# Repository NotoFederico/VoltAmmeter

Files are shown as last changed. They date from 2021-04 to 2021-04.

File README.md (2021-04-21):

# VoltAmmeter

Medidor de tensión y corriente de precisión para fuente de alimentación implementado con placa de desarrollo BLUEPILL (STM32F103)
---

Project.Cover

---

### Download
| Latest release | Latest development build |
|---|---|
|  |  |

---

# Contents
- 1 - [Introduction](#1-introduction)
- 2 - [Downloading the application](#2-downloading-the-game-pre-built)
- 3 - [Building the game](#3-building-the-game)
  - 3.1 - [Building prerequisites](#31-building-prerequisites)
  - 3.2 - [Compiling and running](#32-compiling-and-running)
- 4 - [Contributing](#4-contributing)
- 5 - [Licence](#5-licence)

---

# 1. Introduction

Utiliza un módulo ADS1115 (ADC 16 bits) para la lectura diferencial de corriente y la lectura de tensión de una fuente de alimentación regulable de 0V a 60V y de 0A a 5A.
A través de una comunicación I2C los datos son procesados por el microprocesador a través de un simple algoritmo de promedio de muestras.

Está en curso una segunda versión con tecnologia SMD y se está estudiando implementar un algoritmo que obtenga el promedio de manera mas eficiente

---

# 2. Downloading the application

---

# 3. Building the application

## 3.1 Building prerequisites

---

## 3.2 Compiling and running

---

# 4. Contributing

---
# 5. Licence

Pong Game is licensed under the GNU General Public License version 3.

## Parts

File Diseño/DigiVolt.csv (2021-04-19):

Item | Qty | Reference(s) | Value | Footprint | Available
1 | 3 | AP1, EA1, EV1 | Conn_01x02 | Connectors_Terminal_Blocks:TerminalBlock_Altech_AK300-2_P5.00mm | Yes
2 | 5 | C2, C8, C9, C10, C11 | 0.1u | Capacitors_SMD:C_1206_HandSoldering | No
3 | 2 | C3, C5 | 0.022u | Capacitors_SMD:C_1206_HandSoldering | No
4 | 1 | C4 | 0.22u | Capacitors_SMD:C_1206_HandSoldering | No
5 | 1 | C6 | 3.9n | Capacitors_SMD:C_1206_HandSoldering | No
6 | 1 | J4 | Conn_01x12_Female | Socket_Strips:Socket_Strip_Straight_1x12_Pitch2.54mm | Yes
7 | 1 | J5 | Conn_01x10_Female | Socket_Strips:Socket_Strip_Straight_1x10_Pitch2.54mm | Yes
8 | 2 | J6, J7 | Conn_01x27_Female | Socket_Strips:Socket_Strip_Straight_1x27_Pitch2.54mm | No
9 | 3 | JP1, JP2, JP3 | Jumper | Pin_Headers:Pin_Header_Straight_1x02_Pitch2.54mm | Yes
10 | 1 | R1 | 15k | Resistors_SMD:R_1206_HandSoldering | No
11 | 1 | R2 | 1k | Resistors_SMD:R_1206_HandSoldering | No
12 | 1 | R3 | 0R | Resistors_SMD:R_1206_HandSoldering | No
13 | 1 | R4 | 150k | Resistors_SMD:R_1206_HandSoldering | No
14 | 2 | R5, R6 | 1.2k | Resistors_SMD:R_1206_HandSoldering | No
15 | 2 | R7, R8 | 8.2k | Resistors_SMD:R_1206_HandSoldering | No
16 | 2 | R9, R10 | 100 | Resistors_SMD:R_1206_HandSoldering | No
17 | 1 | R11 | 12k | Resistors_SMD:R_1206_HandSoldering | No
18 | 2 | R12, R13 | 10k | Resistors_SMD:R_1206_HandSoldering | No
19 | 1 | R14 | 100k | Resistors_SMD:R_1206_HandSoldering | No
20 | 1 | RV1 | POT | Potentiometers:Potentiometer_Trimmer_Bourns_3296W | No
21 | 1 | Shunt1 | 0.05 | SMD4527:SMD-1206_Pol | No
22 | 1 | U1 | MC33078 | Housings_DIP:DIP-8_W10.16mm_LongPads | No
23 | 1 | U3 | LM358 | Housings_DIP:DIP-8_W10.16mm_LongPads | No

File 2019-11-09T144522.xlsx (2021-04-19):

Index | Quantity | Part Number | Manufacturer Part Number | Description | Customer Reference | Available | Backorder | Unit Price | Extended Price USD
1 | 4 | 732-7914-1-ND | 885012106017 | CAP CER 1UF 16V X5R 0603 |  | 4 | 0 | 0.15 | 0.60
2 | 1 | 811-3014-ND | OKI-78SR-3.3/1.5-W36H-C | DC DC CONVERTER 3.3V 5W |  | 1 | 0 | 4.3 | 4.30
3 | 1 | 811-2692-ND | OKI-78SR-5/1.5-W36H-C | DC DC CONVERTER 5V 8W |  | 1 | 0 | 4.3 | 4.30
4 | 4 | A126389CT-ND | CRG0805F8K2 | RES SMD 8.2K OHM 1% 1/8W 0805 |  | 4 | 0 | 0.1 | 0.40
5 | 4 | A129737CT-ND | CRGCQ0805F100R | CRGCQ 0805 100R 1% |  | 4 | 0 | 0.1 | 0.40
6 | 10 | A129761CT-ND | CRGCQ0805F10K | CRGCQ 0805 10K 1% |  | 10 | 0 | 0.051 | 0.51
7 | 2 | MCP6241T-E/SNCT-ND | MCP6241T-E/SN | IC OPAMP GP 1 CIRCUIT 8SOIC |  | 2 | 0 | 0.3 | 0.60
8 | 10 | 311-1338-1-ND | CC0402KRX7R7BB104 | CAP CER 0.1UF 16V X7R 0402 |  | 10 | 0 | 0.03 | 0.30
9 | 2 | A129763CT-ND | CRGCQ0805F15K | CRGCQ 0805 15K 1% |  | 2 | 0 | 0.1 | 0.20
10 | 2 | A126340CT-ND | CRG0805F150K | RES SMD 150K OHM 1% 1/8W 0805 |  | 2 | 0 | 0.1 | 0.20
11 | 2 | A129749CT-ND | CRGCQ0805F1K0 | CRGCQ 0805 1K0 1% |  | 2 | 0 | 0.1 | 0.20
12 | 4 | A126346CT-ND | CRG0805F1K2 | RES SMD 1.2K OHM 1% 1/8W 0805 |  | 4 | 0 | 0.1 | 0.40
13 | 2 | 311-1.50MCRCT-ND | RC0805FR-071M5L | RES SMD 1.5M OHM 1% 1/8W 0805 |  | 2 | 0 | 0.1 | 0.20
14 | 2 | 497-8716-1-ND | LD39050PU33R | IC REG LINEAR 3.3V 500MA 6DFN |  | 2 | 0 | 1.09 | 2.18
15 | 2 | 505-AD8628WARZ-R7CT-ND | AD8628WARZ-R7 | IC OPAMP ZERO-DRIFT 1 CIRC 8SOIC |  | 2 | 0 | 2.87 | 5.74
16 | 1 | AZ1117EH-3.3TRG1DICT-ND | AZ1117EH-3.3TRG1 | IC REG LINEAR 3.3V 1A SOT223 |  | 1 | 0 | 0.42 | 0.42
17 | 1 | AZ1117EH-5.0TRG1DICT-ND | AZ1117EH-5.0TRG1 | IC REG LINEAR 5V 1A SOT223 |  | 1 | 0 | 0.42 | 0.42

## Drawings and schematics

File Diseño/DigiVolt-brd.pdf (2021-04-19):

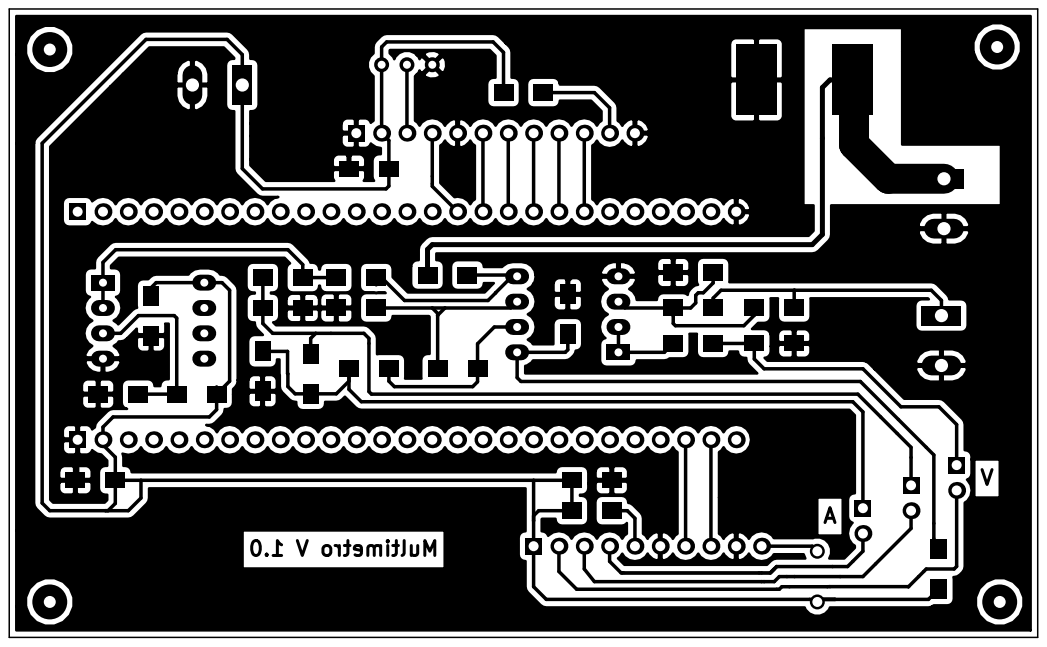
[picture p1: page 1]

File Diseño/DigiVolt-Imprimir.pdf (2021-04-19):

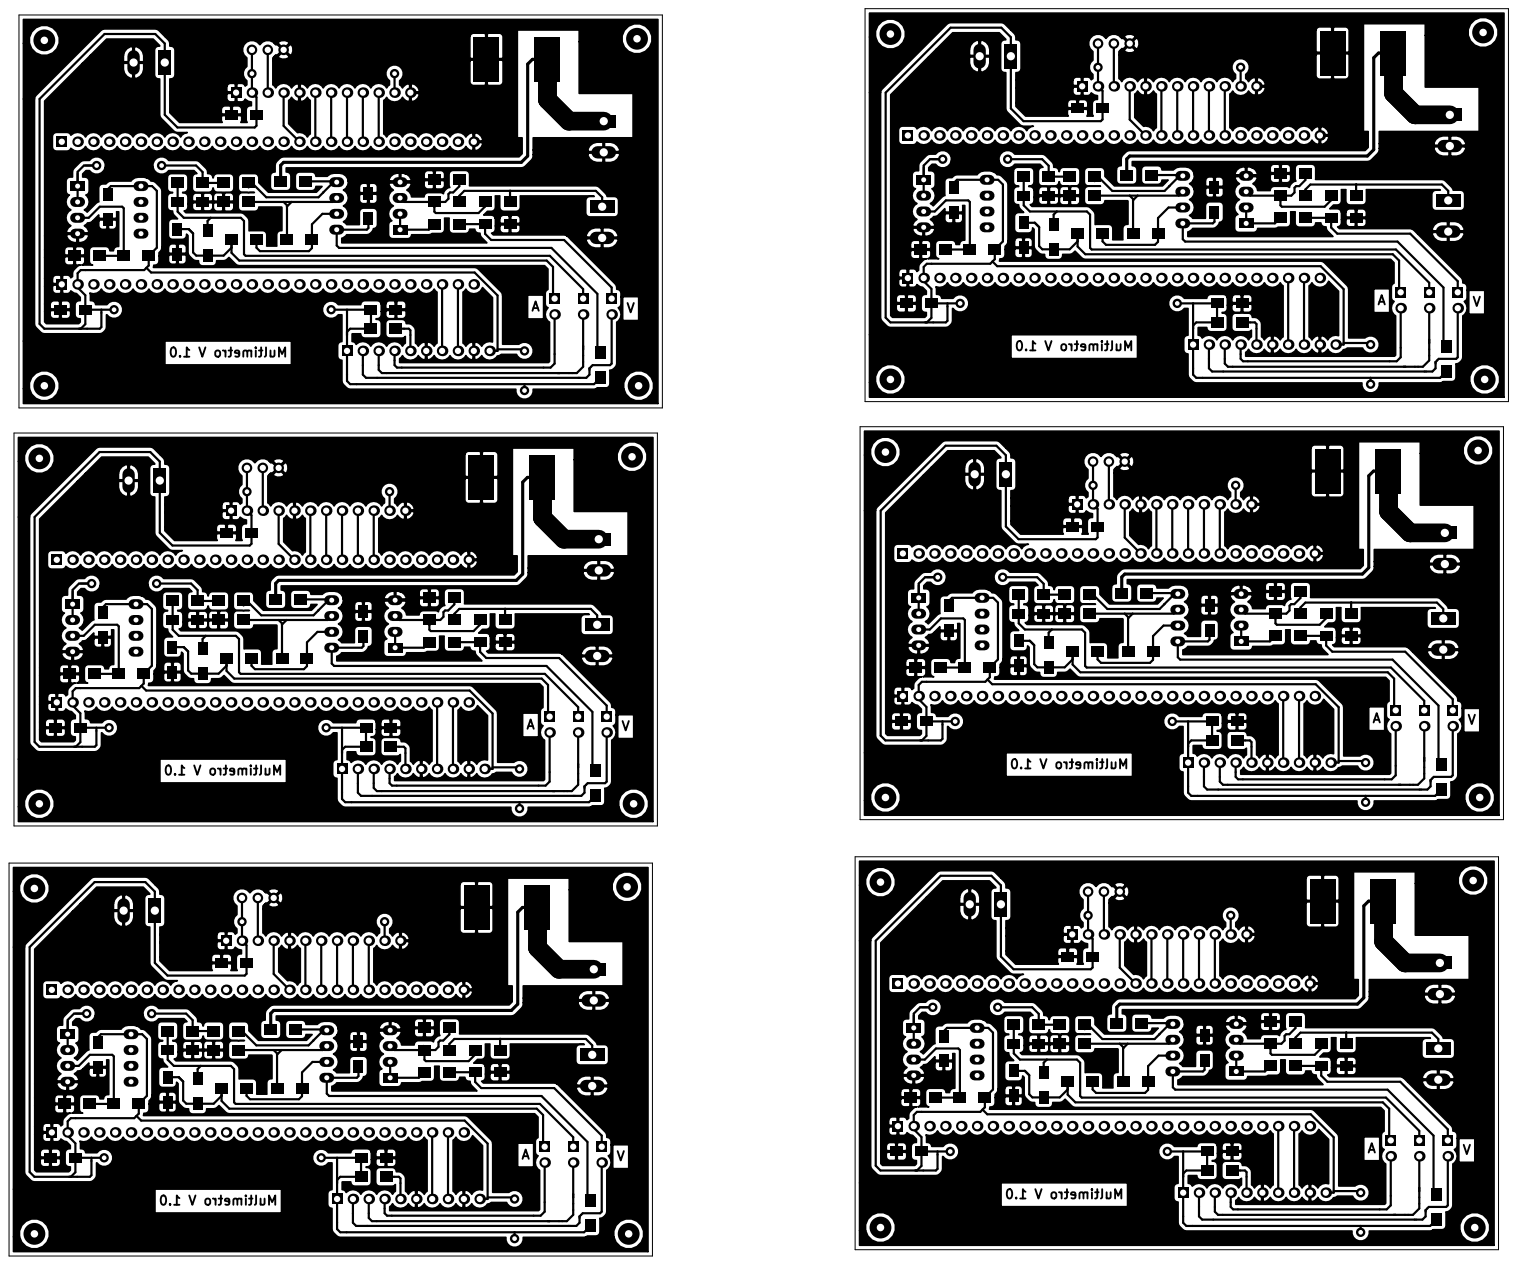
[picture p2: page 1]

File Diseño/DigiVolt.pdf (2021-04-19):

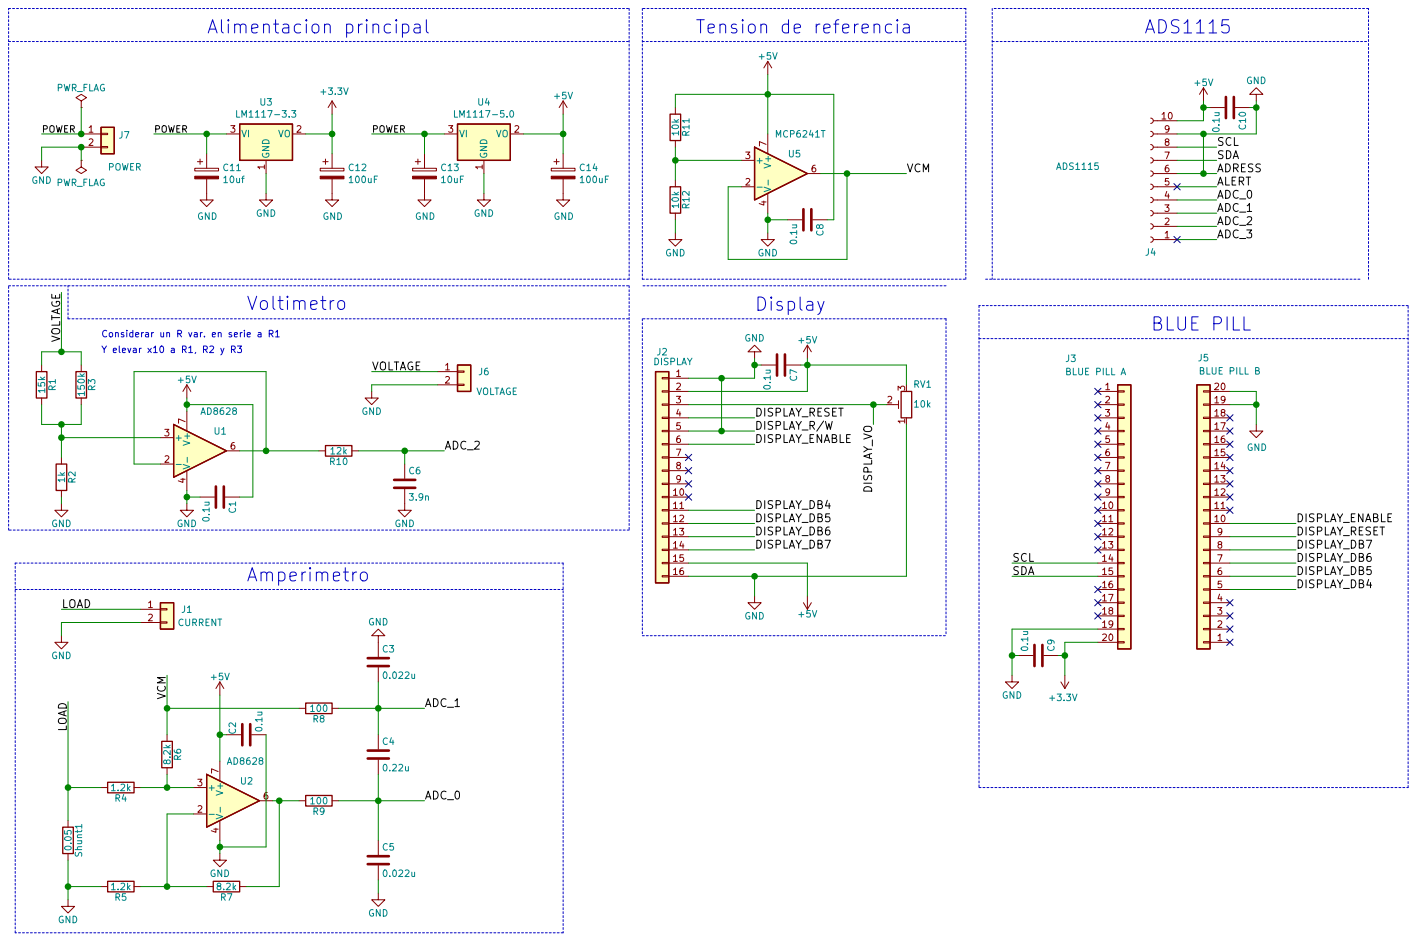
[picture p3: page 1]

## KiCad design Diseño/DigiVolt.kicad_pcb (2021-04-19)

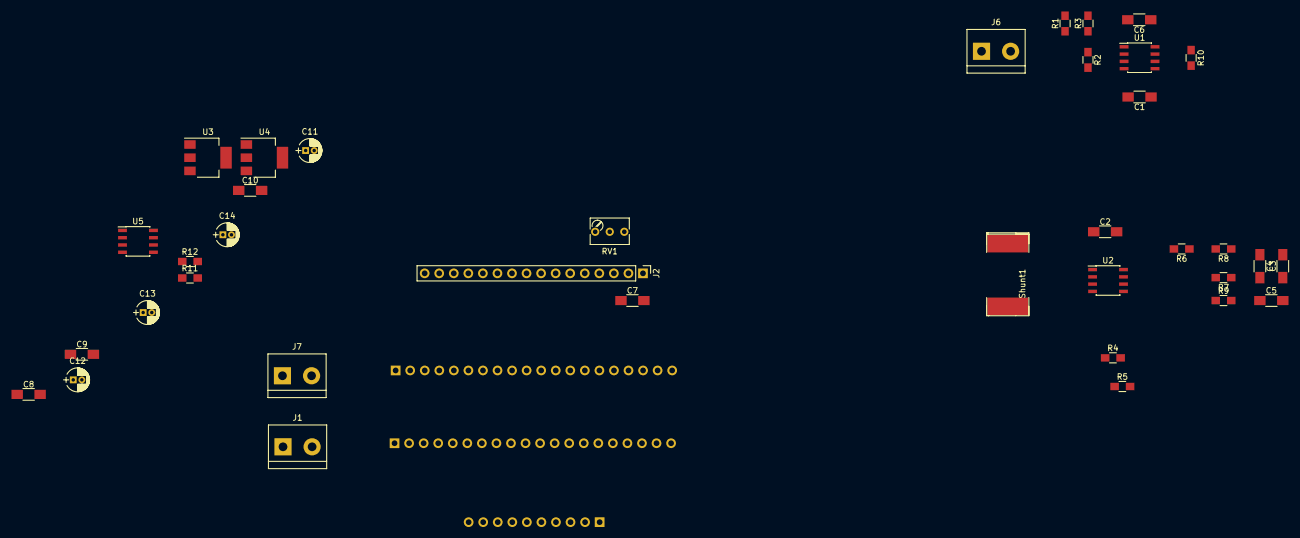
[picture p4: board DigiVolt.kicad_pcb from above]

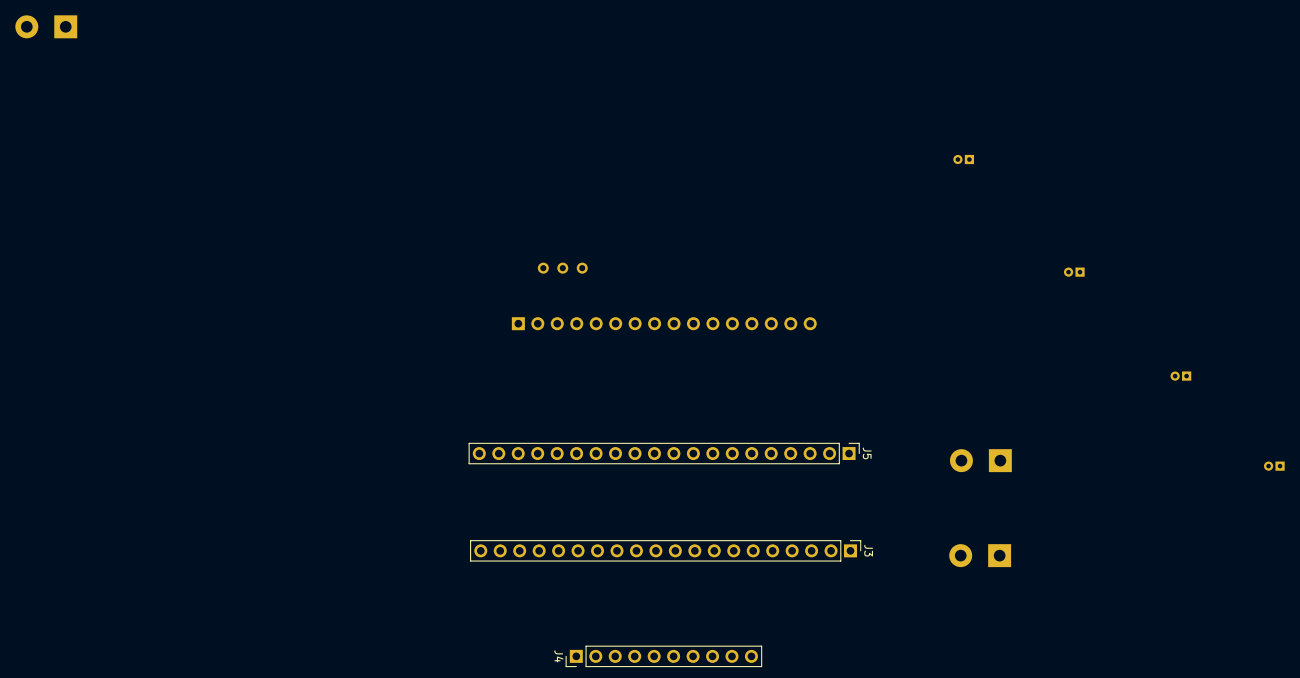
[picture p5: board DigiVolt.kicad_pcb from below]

Board: 4 copper layers, 40 parts (3 on the bottom side), 25 nets, no tracks yet.

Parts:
C1, C2, C7, C8, C9, C10: 0.1u; C_1206_HandSoldering
C3, C5: 0.022u; C_1206_HandSoldering
C4: 0.22u; C_1206_HandSoldering
C6: 3.9n; C_1206_HandSoldering
C11: 10uf; CP_Radial_D4.0mm_P1.50mm
C12, C14: 100uF; CP_Radial_D4.0mm_P1.50mm
C13: 10uF; CP_Radial_D4.0mm_P1.50mm
J1: CURRENT; TerminalBlock_bornier-2_P5.08mm
J2: DISPLAY; Socket_Strip_Straight_1x16_Pitch2.54mm
J3: BLUE PILL A; Socket_Strip_Straight_1x20_Pitch2.54mm
J4: ADS1115; Socket_Strip_Straight_1x10_Pitch2.54mm
J5: BLUE PILL B; Socket_Strip_Straight_1x20_Pitch2.54mm
J6: VOLTAGE; TerminalBlock_bornier-2_P5.08mm
J7: POWER; TerminalBlock_bornier-2_P5.08mm
R1: 15k; R_0805_HandSoldering
R2: 1k; R_0805_HandSoldering
R3: 150k; R_0805_HandSoldering
R4, R5: 1.2k; R_0805_HandSoldering
R6, R7: 8.2k; R_0805_HandSoldering
R8, R9: 100; R_0805_HandSoldering
R10: 12k; R_0805_HandSoldering
R11, R12: 10k; R_0805_HandSoldering
RV1: 10k; Potentiometer_Trimmer_Bourns_3266Y
Shunt1: 0.05; SMD-1206_Pol
U1, U2: AD8628; SOIC-8_3.9x4.9mm_Pitch1.27mm
U3: LM1117-3.3; SOT-223-3_TabPin2
U4: LM1117-5.0; SOT-223-3_TabPin2
U5: ‎MCP6241T; SOIC-8_3.9x4.9mm_Pitch1.27mm

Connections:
+3V3: C9.1, C12.1, J3.20, U3.2
+5V: C1.1, C2.2, C7.1, C8.1, C10.2, C14.1, J2.2, J2.15, J4.10, R11.1, RV1.3, U1.7, U2.7, U4.2, U5.7
/ADC_0: C4.2, C5.1, J4.4, R9.1
/ADC_1: C3.2, C4.1, J4.3, R8.1
/ADC_2: C6.1, J4.2, R10.1
/DISPLAY_DB4: J2.11, J5.5
/DISPLAY_DB5: J2.12, J5.6
/DISPLAY_DB6: J2.13, J5.7
/DISPLAY_DB7: J2.14, J5.8
/DISPLAY_ENABLE: J2.6, J5.10
/DISPLAY_RESET: J2.4, J5.9
/DISPLAY_VO: J2.3, RV1.2
/LOAD: J1.1, R4.2, Shunt1.1
/POWER: C11.1, C13.1, J7.1, U3.3, U4.3
/SCL: J3.14, J4.8
/SDA: J3.15, J4.7
/VCM: R6.1, R8.2, U5.2, U5.6
/VOLTAGE: J6.1, R1.1, R3.1
GND: C1.2, C2.1, C3.1, C5.2, C6.2, C7.2, C8.2, C9.2, C10.1, C11.2, C12.2, C13.2, C14.2, J1.2, J2.1, J2.5, J2.16, J3.19, J4.6, J4.9, J5.19, J5.20, J6.2, J7.2, R2.2, R5.2, R12.2, RV1.1, Shunt1.2, U1.4, U2.4, U3.1, U4.1, U5.4
unnamed: R1.2, R2.1, R3.2, U1.3
unnamed: R4.1, R6.2, U2.3
unnamed: R5.1, R7.2, U2.2
unnamed: R7.1, R9.2, U2.6
unnamed: R10.2, U1.2, U1.6
unnamed: R11.2, R12.1, U5.3

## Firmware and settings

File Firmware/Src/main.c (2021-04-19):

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

/* Includes ------------------------------------------------------------------*/
#include "main.h"

/* USER CODE BEGIN Includes */
#include "lcd.h"
#include "Fuente_VA.h"
/* USER CODE END Includes */

I2C_HandleTypeDef hi2c1;

void SystemClock_Config(void);
static void MX_GPIO_Init(void);
static void MX_I2C1_Init(void);
/**
  * @brief  The application entry point.
  * @retval int
  */
int main(void)
{
  /* MCU Configuration--------------------------------------------------------*/

  /* Reset of all peripherals, Initializes the Flash interface and the Systick. */
  HAL_Init();

  /* Configure the system clock */
  SystemClock_Config();

  /* Initialize all configured peripherals */
  MX_GPIO_Init();
  MX_I2C1_Init();
  /* USER CODE BEGIN 2 */
		//HAL_I2C_Init(&hi2c1);
		init_lcd();
		cls_lcd();
		//Imprimir titulos en display
		print1("Voltage:");
		posic_lcd(0x00+17);
		print("[V]");
		print2("Current:");
		posic_lcd(0x40+17);
		print("[A]");
		print3("Power:");
		posic_lcd(0x14+17);
		print("[W]");
		print4("Device Under Test OK");
  /* USER CODE END 2 */

  /* Infinite loop */
  /* USER CODE BEGIN WHILE */
  while (1)
  {
    /* USER CODE END WHILE */
	
		ADS1115_Update();
		
    /* USER CODE BEGIN 3 */
  }
  /* USER CODE END 3 */
}

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


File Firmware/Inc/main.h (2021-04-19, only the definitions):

#define LED_Pin GPIO_PIN_13
#define LED_GPIO_Port GPIOC
#define LCD_D4_Pin GPIO_PIN_0
#define LCD_D4_GPIO_Port GPIOA
#define LCD_D5_Pin GPIO_PIN_1
#define LCD_D5_GPIO_Port GPIOA
#define LCD_D6_Pin GPIO_PIN_2
#define LCD_D6_GPIO_Port GPIOA
#define LCD_D7_Pin GPIO_PIN_3
#define LCD_D7_GPIO_Port GPIOA
#define LCD_RS_Pin GPIO_PIN_4
#define LCD_RS_GPIO_Port GPIOA
#define LCD_EN_Pin GPIO_PIN_5
#define LCD_EN_GPIO_Port GPIOA

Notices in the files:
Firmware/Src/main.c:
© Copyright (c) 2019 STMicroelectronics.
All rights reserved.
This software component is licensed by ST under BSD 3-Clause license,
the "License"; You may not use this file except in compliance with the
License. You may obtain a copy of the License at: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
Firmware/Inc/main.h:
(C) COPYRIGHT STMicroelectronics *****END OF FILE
